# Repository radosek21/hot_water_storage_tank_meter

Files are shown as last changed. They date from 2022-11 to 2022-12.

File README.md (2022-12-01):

# Měřidlo nabití akumulační nádrže
Když jsem si do svého domu nainstaloval topení s kotlem na tuhá paliva a akumulační nádrží Dražice NADO 750/200 v1, celkem mně zajímalo, jak se nádrž chová při nabíjení, vybíjení a v klidu. Dále mne zajímaly tepelné úniky a jak se vrství teplota v nádrži. V neposlední řadě bych ocenil, kdybych dokázal spočítat a ukázat procentuální nabití nádoby pro snazší odhad, kdy se má znovu zatopit.

Dražice NADO 750/200 v1 kombinuje akumulační nádrž topení a zásobník TUV. Disponuje dvěma jímkami pro teplotní čidla. Už při prvních pokusech měření teploty jsem zjistil, že měření pouze se dvěma čidly je pro mé účely naprosto nedostačující. Proto jsem zabrouzdal na internetu a pokusil se najít, zda někdo neřešil podobný problém. Bohužel se mi nepodařilo najít hotové řešení. Ale v nějaké diskuzi jsem narazil na příspěvek, kde diskutér popsal nápad o přilepení několika teplotních čidel přímo na povrch nádoby. Nechal jsem se tímto nápadem inspirovat a sestavil jsem jednoduché měřidlo. S velkým překvapením to překonalo mé očekávání.

## Čidla

Jako první jsem se pustil do čidel. Použil jsem 10 kusů čidel DS18B20, které jsem zapojil paralelně na tří-žílovou duhovou kšandu. Délku kšandy (resp. vzdálenost prvního čidla od posledního) jsem zvolil stejnou, jako je rozteč jímek čidel na nádrži. V mém případě 1049 mm. Tedy při počtu 10ti čidel je rozteč mezi jednotlivými čidly 116,5 mm. Pomocí ALU lepící pásky jsem čidla přilepil k povrchu nádrže tak, aby první a poslední čidlo bylo ve stejné úrovni, jako jsou jímky. Viz obrázek.

Pozn. Bacha na levné čínské kopie DS18B20. Nechal jsem se nachytat a koupil jsem 20ks podezřele levných čidel z eBay. Odchylka od skutečné teploty byla 6-9K. Čidla jsem si pak musel zkalibrovat podle přesnějšího referenčního teploměru. Do firmware jsem proto doplnil proměnnou pro korekci čidel. Více o kopiích DS18B20 je popsáno třeba zde: https://github.com/cpetrich/counterfeit_DS18B20

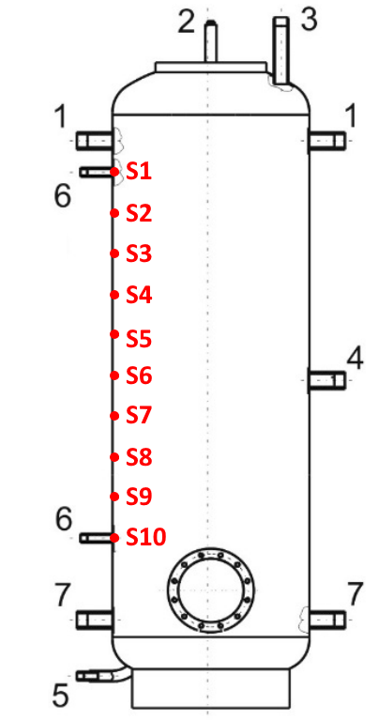
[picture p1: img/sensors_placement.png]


## Měřidlo

Pro sběr a vyhodnocení dat jsem použil modul Arduino Wemos kompatibilní. Modul má integrovanou WiFi a má dostatečný počet GPIO. Jako zobrazovač jsem použil Arduino hodinový displej s řadičem TM1637. Aby to nejen fungovalo, ale i vypadalo, vytisknul jsem si na 3d tiskárně malou krabičku, do které se vše pohodlně vejde. Data pro 3d tisk jsou v adresáři *housing*.

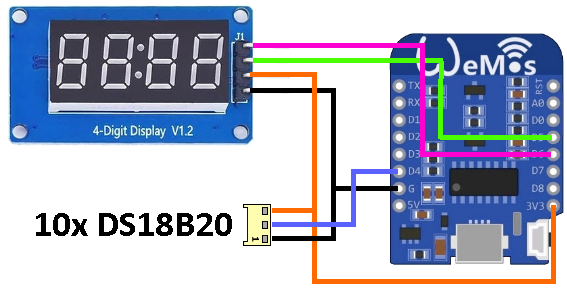
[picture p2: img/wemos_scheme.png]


Schéma zapojení měřidla

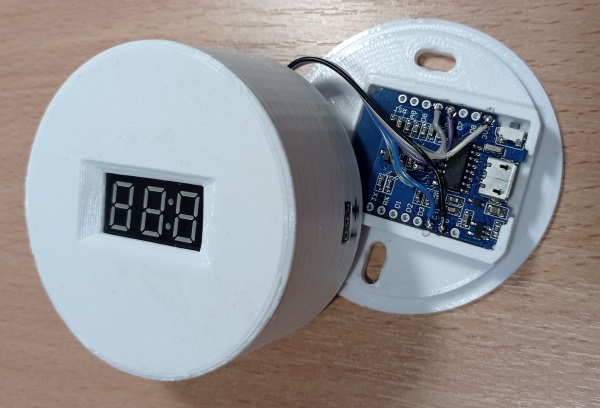
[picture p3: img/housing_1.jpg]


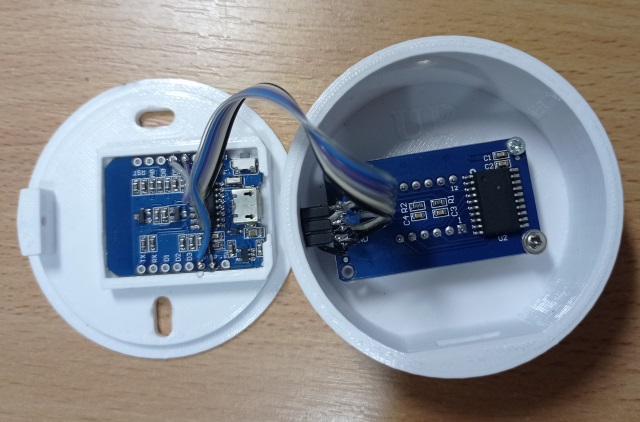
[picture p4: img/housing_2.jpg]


Vnitřní zapojení krabičky

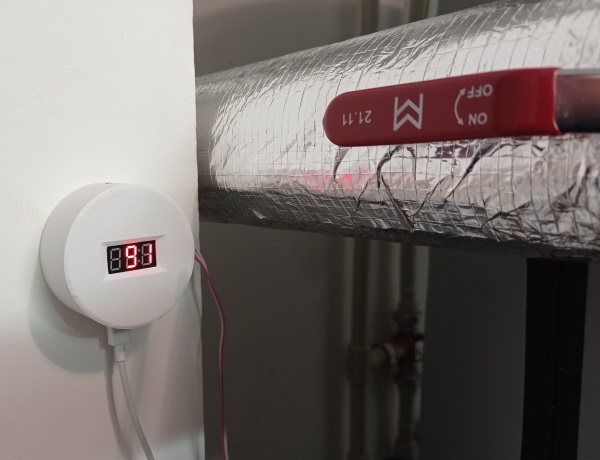
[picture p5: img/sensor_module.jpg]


Měřidlo v provozu

## Fimware pro Wemos

Zdrojové kódy měřidla se nacházejí v adresáři *wemos_18B20_sensor*. Projektový soubor *wemos_18B20_sensor.ino* zajišťuje funkčnost a soubory *peripherals.cpp* a *peripherals.h* zajišťují obsluhu teplotních čidel a displeje. Aby bylo možné zkompilovat tento projekt, je zapotřebí do Aurduino IDE doinstalovat podporu desky esp8266 a následně vybrat správnou Arduino desku. V mém případě **LOLIN(WEMOS) D1 mini (clone)**, který jsem kopil na eBay. 

Dále je zapotřebí doinstalovat knihovny:

-  TM1637 - Grove 4-Digital Display by Seeed Studio
- OneWire by Paul Stroffregen
- DallasTemperature by Miles Burton

Ve zdrojovém kódu je zapotřebí doplnit:

- SSID a heslo WiFi, do které se bude měřidlo připojovat
- seznam adresy všech deseti čidel DS18B20 (seznam **sensorsAddr[TEMP_SENSORS_CNT]**)
- případné korekce čidel (seznam **sensorsCorrections[TEMP_SENSORS_CNT]**)

Veškerá měřená i vypočtená data z čidel jsou dostupná přes ModbusTCP (port 502).

#### Input registry:

| Jméno registru | Adresa | Jednotka | Popis |
| --- | --- | --- | --- |
| Sensors count | 1 | | Počet právě dostupných čidel DS18B20 |
| Average temperature | 2 | 0.01°C | Průměrná teplota všech čidel |
| Capacity | 3 | 0.01% | Procentuální nabití nádrže |
| Sensors data | 100..109 | 0.01°C | Teploty jednotlivých čidel S1 - S10  |

#### Holding registry:

| Jméno registru | Adresa | Jednotka | Popis |
| --- | --- | --- | --- |
| Min average temperature | 1 | 1°C | Nejnižší průměrná teplota v nádrži pro výpočet nabití. Parametr **MinAvgTemp** |
| Max average temperature | 2 | 1°C | Nevyšší průměrná teplota v nádrži pro výpočet nabití. Parametr **MaxAvgTemp** |

Konfigurační parametry min a max average temperature jsou uloženy ve vnitřní EEPROM procesoru. Jejich defaultní hodnoty jsou 40 a 77°C.

## Sběr dat

Pro snadný sběr a následnou analýzu dat jsem napsal jednoduchý Python skript, který každých 10s periodicky vyčítá data z měřidla a ukládá je do MySQL (resp. MariaDb) databáze. Použití relační databáze pro tyto účely není úplně šťastné, ale u mne doma to bylo nejsnazší řešení, protože můj NAS server ji nativně podporuje. Pro omezení počtu mysql queries skript posílá nasbíraná data jednou za minutu. Zdrojové kódy se nacházejí v adresáři *data_acquire*. Hlavní program se nachází v souboru *HeaterDAQ.py*. V tomto souboru je třeba doplnit následující:

- mysql.host - adresa MySQL serveru
- mysql.user - uživatelské jméno do databáze
- mysql.passwd - heslo do databáze
- dbName - jméno databáze, do které se budou ukládat data
- dbTable - tabulka výše zmíněné databáze, do které se budou ukládat data

## Analýza dat a výpočet nabití nádrže

K analýze a vizualizaci dat jsem použil Grafanu. Nabízí dost možností a funkcí pro práci s daty. 

Pro výpočet procentuálního nabití nádrže jsem po zvážení několika algoritmů dospěl k závěru, že nejvhodnějším, a také nejjednodušším, řešením je použití obyčejného aritmetického průměru teplot všech čidel a následná transformace lineární funkcí na procenta. Algoritmus je výpočetně velmi jednoduchý a má dostatečnou přesnost a stabilitu.

Výpočet vypadá následovně:
$$
cap = (avg[S1:S10] - MinAvgTemp) / (MaxAvgTemp  - MinAvgTemp) * 100
$$

Parametry **MaxAvgTemp** a **MinAvgTemp** jsou v uloženy ve vnitřní paměti EEPROM procesoru. Jsou konfigurovatelné pomocí holding registrů 1 a 2.

Data z Grafany pak vypadají například takto:

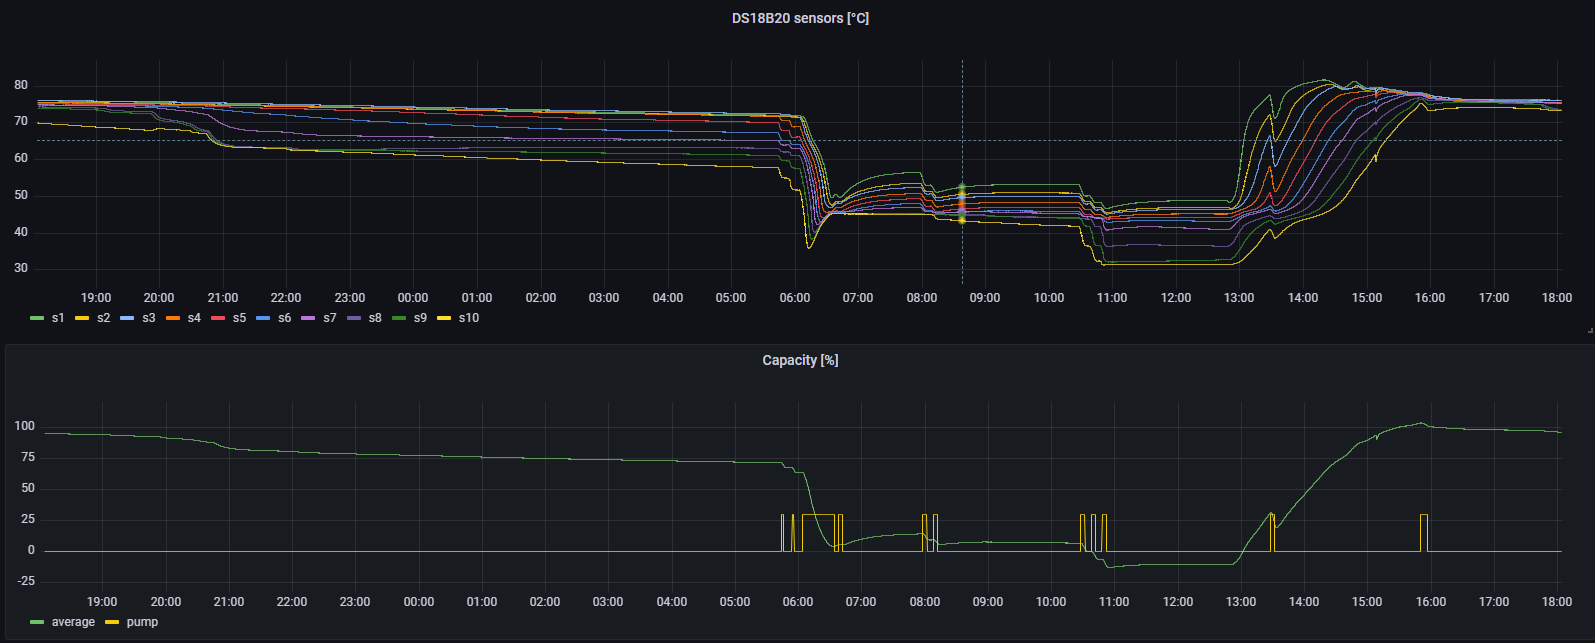
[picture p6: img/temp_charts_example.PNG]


Horní graf ukazuje data z jednotlivých čidel. Dolní graf ukazuje procentuální nabití nádrže a cykly spínání oběhového čerpadla. V grafech je od začátku viděl pozvolné vybíjení nádrže vlivem teplených ztrát. V cca 21hod je vidět drobný odběr teplé vody a v 6 hod ráno se sepnulo oběhové čerpadlo a topilo na komfortní teplotu. Následně ve 13 hod jsem zatopil v kotli. 

## Závěr

Nejen v grafech z Grafany je vidět, že měřidlo teploty ukazuje teplotu poměrně dobře. Výpočet procentuálního nabití nádrže odpovídá aktuálnímu stavu a z grafu je patrné, že tato hodnota nijak nekolísá a je velmi stabilní. Měřidlo nadmíru splnilo mé očekávání a informace na displeji je natolik intuitivní, že to pochopila i moje žena. Inu, i z malého nápadu se dá udělat celkem hezký projekt. ;-)

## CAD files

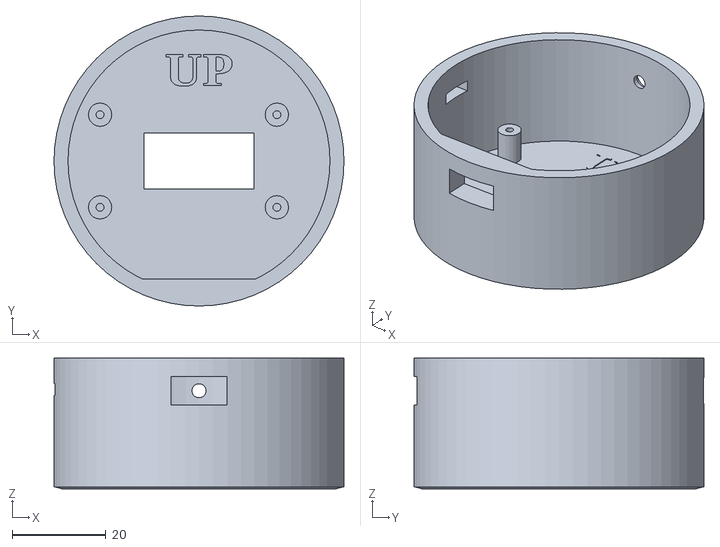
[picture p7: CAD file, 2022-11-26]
housing/Tank capacity meter cover.stl
62.0 x 62.0 x 28.0

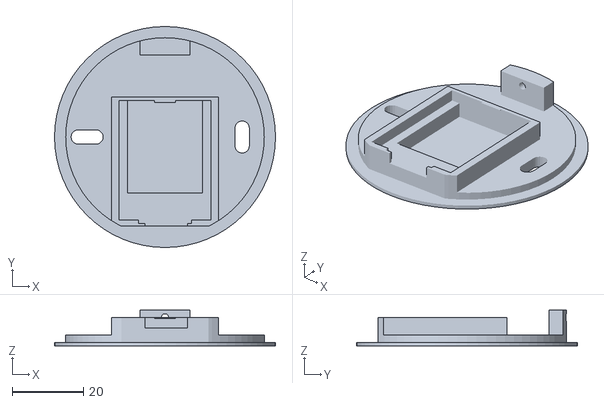
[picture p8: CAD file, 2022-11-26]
housing/Tank capacity meter base.stl
62.0 x 62.0 x 10.0

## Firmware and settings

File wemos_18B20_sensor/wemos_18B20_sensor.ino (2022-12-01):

// LOLIN(WEMOS) D1 mini (clone)

#include <ESP8266WiFi.h>
#include <ModbusIP_ESP8266.h>
#include "peripherals.h"
#include <EEPROM.h>

#define EEPROM_MAGIC_NUMBER                 0xDEADBEEF
#define DEFAULT_HEATER_TANK_MIN_AVG_TEMP    40
#define DEFAULT_HEATER_TANK_MAX_AVG_TEMP    77

#define MB_IREG_SENSORS_CNT_ADDR   1
#define MB_IREG_AVG_TEMP_ADDR      2
#define MB_IREG_CAPACITY_ADDR      3
#define MB_IREG_SENSORS_ADDR       100
#define MB_HREG_MIN_TEMP_ADDR      1
#define MB_HREG_MAX_TEMP_ADDR      2


typedef struct {
  uint32_t magic;
  uint16_t minAvgTemp;
  uint16_t maxAvgTemp;
} EepromData_t;


// Set WiFi credentials
#define WIFI_SSID "MY SSID"
#define WIFI_PASS "MY PASSWORD"

// List of the temperature sensors addresses
String sensorsAddr[TEMP_SENSORS_CNT] = {
  "2801ED0F00000085",
  "283AEC0F0000005D",
  "285BF60F00000068",
  "2827FF0F0000007E",
  "28D7FD0F0000008F",
  "2870FB0F000000CA",
  "2804F10F00000033",
  "2819FE0F0000004D",
  "28A2F00F00000010",
  "28CDF70F000000A6",
};

// Put temperature corrections here, if needed.
float sensorsCorrections[TEMP_SENSORS_CNT] = {
  0,
  0,
  0,
  0,
  0,
  0,
  0,
  0,
  0,
  0,
};

ModbusIP mb;
long ts;
EepromData_t eepromData;
uint16_t iRegAvgTemp;
uint16_t iRegSensorsCnt;

void setup() {
  int timeout = millis() + 60000;
  iRegAvgTemp = 0;
  iRegSensorsCnt = 0;
  Serial.begin(115200);
  Serial.println("");
  
  
  delay(1000);
  readParams();
  tempSensors.begin();

  // Begin WiFi
  WiFi.begin(WIFI_SSID, WIFI_PASS);
  // Connecting to WiFi...
  Serial.print("Connecting to ");
  Serial.print(WIFI_SSID);
  // Loop continuously while WiFi is not connected
  while ((WiFi.status() != WL_CONNECTED) && (millis() < timeout)) {
    delay(100);
    Serial.print(".");
    display.progressIter();
  }

  Serial.println();
  if (WiFi.status() != WL_CONNECTED) {
    Serial.print("Connected! IP address: ");
    Serial.println(WiFi.localIP());
  } else {
    Serial.println("WIFI connection timed out!");
  }

  // Start Modbus TCP server
  mb.server();    
  // Register modbus input registers
  mb.addIreg(MB_IREG_SENSORS_CNT_ADDR, 0);
  mb.addIreg(MB_IREG_AVG_TEMP_ADDR, 0);
  mb.addIreg(MB_IREG_CAPACITY_ADDR, 0);
  mb.addIreg(MB_IREG_SENSORS_ADDR, 0, TEMP_SENSORS_CNT); 
  mb.addHreg(MB_HREG_MIN_TEMP_ADDR, eepromData.minAvgTemp);
  mb.addHreg(MB_HREG_MAX_TEMP_ADDR, eepromData.maxAvgTemp);
  mb.onSetHreg(MB_HREG_MIN_TEMP_ADDR, cbWriteMinTemp, 1);
  mb.onSetHreg(MB_HREG_MAX_TEMP_ADDR, cbWriteMaxTemp, 1);
  
  // Bind all DS18B20 temperature sensors
  for (int index = 0; index < TEMP_SENSORS_CNT; index++) {
    DeviceAddress addr;
    for (int i = 0; i < 8; i++ ) {
      addr[i] = StrToHex(sensorsAddr[index].substring(i*2, i*2+2)); 
    }
    if (!tempSensors.bind(addr, index)) {
      Serial.print("Sensor address ");
      Serial.print(sensorsAddr[index]);
      Serial.println(" not bound!!!");
    }
  }
  ts = millis();
}

void loop() {
  float temp;
  float avgTemp = 0;
  int avgCnt = 0;
  float heatCap;
  
  // Modbus TCP handler
  mb.task();
  
  //Read every two seconds
  if (millis() >= ts) {
    // Schedule next temperature sensors reading
    ts = millis() + 2000;
    
    // Send command to all the sensors for temperature conversion
    tempSensors.requestTemperatures();
    // 
    for (int i = 0;  i < TEMP_SENSORS_CNT;  i++) {
      temp = tempSensors.getTemp(i) + sensorsCorrections[i];
      // If temperature value is valid
      if ((temp > 0) && (temp < 120)) {
        Serial.print("Sensor ");
        Serial.print(i+1);
        Serial.print(" : ");
        Serial.print(temp);
        Serial.println("C");
        mb.Ireg(MB_IREG_SENSORS_ADDR + i, (int16_t)(temp * 100));
        avgTemp += temp;
        avgCnt++;
      }
    }
    mb.Ireg(MB_IREG_SENSORS_CNT_ADDR, avgCnt);  
    if (avgCnt > (TEMP_SENSORS_CNT / 2)) {
      // Do an average temperature when at least half of sensors are present
      avgTemp /= avgCnt;
      // Transform measured temperature value to the percentage of heater tank capacity
      heatCap = ((avgTemp - eepromData.minAvgTemp) * 100 / (eepromData.maxAvgTemp - eepromData.minAvgTemp));
      mb.Ireg(MB_IREG_AVG_TEMP_ADDR, (int16_t)(avgTemp * 100));
      mb.Ireg(MB_IREG_CAPACITY_ADDR, (int16_t)(heatCap * 100));
      // Show current capacity
      display.number((int)constrain(heatCap, -150, 999), 1);
    } else {
      // Half of sensors are missed. Display "---"
      display.code(display.emptyPattern);
      mb.Ireg(MB_IREG_AVG_TEMP_ADDR, 0);
      mb.Ireg(MB_IREG_CAPACITY_ADDR, 0);
    }
  }
}

int StrToHex(String str) {
  char buf[3];
  str.toCharArray(buf, 3);
  return (int)strtol(buf, 0, 16);
}

void readParams()
{
  //Init EEPROM
  EEPROM.begin(sizeof(EepromData_t));
  Serial.println("EEPROM: reading");
  EEPROM.get(0, eepromData);
  if(eepromData.magic != EEPROM_MAGIC_NUMBER) {
    Serial.println("EEPROM: using defaults.");
    eepromData.magic = EEPROM_MAGIC_NUMBER;
    eepromData.minAvgTemp = DEFAULT_HEATER_TANK_MIN_AVG_TEMP;
    eepromData.maxAvgTemp = DEFAULT_HEATER_TANK_MAX_AVG_TEMP;
  }
  EEPROM.end();
}

void writeParams()
{
  //Init EEPROM
  Serial.println("EEPROM: writing");
  EEPROM.begin(sizeof(EepromData_t));
  EEPROM.put(0, eepromData);
  EEPROM.commit();
  EEPROM.end();
}

uint16_t cbWriteMinTemp(TRegister* reg, uint16_t val) {
  Serial.print("Write min temp: ");
  Serial.println(val);
  eepromData.minAvgTemp = val;
  writeParams();
  return val;
}

uint16_t cbWriteMaxTemp(TRegister* reg, uint16_t val) {
  Serial.print("Write max temp: ");
  Serial.println(val);
  Serial.println(val);
  eepromData.maxAvgTemp = val;
  writeParams();
  return val;
}

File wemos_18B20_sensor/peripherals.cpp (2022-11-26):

#include "peripherals.h"


#define TM1637_CLK    ( D6 )
#define TM1637_DIO    ( D5 )


//-------------------------------------------------------------------------
// Display
//-------------------------------------------------------------------------
Display::Display():
tm(TM1637_CLK, TM1637_DIO),
progressCnt(0)
{
  tm.init();
  tm.set(2); // Set brightness level
}

void Display::code(uint8_t BitAddr, int8_t code)
{
  tm.start();          //start signal sent to TM1637 from MCU
  tm.writeByte(ADDR_FIXED);//
  tm.stop();           //
  tm.start();          //
  tm.writeByte(BitAddr|0xc0);//
  tm.writeByte(code + ((tm._PointFlag == POINT_ON) ? 0x80 : 0x00));//
  tm.stop();            //
  tm.start();          //
  tm.writeByte(tm.Cmd_DispCtrl);//
  tm.stop();           //
}

void Display::code(const uint8_t *codes)
{
  code((uint8_t*)codes);
}

void Display::code(uint8_t *codes)
{
  for (int i=0; i < 4; i++) {
     code(i, codes[i]);
  }
}

void Display::number(int num, int pos)
{
  tm.point(false);
  for (int i = 0; i < pos; i++) {
    code(4-pos, DISP_CHAR_Empty);
  }
  if (num >= 1) {
    tm.display(3-pos, num % 10);
  } else {
    code(3-pos, DISP_CHAR_Empty);
  }
  if (num >= 10) {
    tm.display(2-pos, num / 10 % 10);   
  } else {
    code(2-pos, DISP_CHAR_Empty);
  }
  if (num >= 100) {
    tm.display(1-pos, num / 100 % 10);   
  } else {
    code(1-pos, DISP_CHAR_Empty);
  }
  if (num >= 1000) {
    tm.display(0-pos, num / 1000 % 10);
  } else {
    code(0-pos, DISP_CHAR_Empty);
  }
}

void Display::progressIter()
{
  for (int i = 0; i < DISP_COUNT; i++) {
    code(i, progressPattern[progressCnt][i]);
  }
  progressCnt++;
  if (progressCnt >= 10) {
    progressCnt = 0;
  }
}

//-------------------------------------------------------------------------
// Temperature sensors
//-------------------------------------------------------------------------
TempSensors::TempSensors():
oneWire(2),
ds18b20(&oneWire)
{

}

void TempSensors::begin()
{
  memset(bindings, 255, TEMP_SENSORS_CNT);
  ds18b20.begin();
  Serial.println("Locating devices...");
  Serial.print("Found ");
  deviceCount = ds18b20.getDeviceCount();
  Serial.print(deviceCount, DEC);
  Serial.println(" devices.");
  Serial.println("");
  Serial.println("Printing addresses...");
  for (int i = 0;  i < deviceCount;  i++) {
    Serial.print("Sensor ");
    Serial.print(i+1);
    Serial.print(" : ");
    ds18b20.getAddress(deviceAddress[i], i);
    printAddress(deviceAddress[i]);
  }
}

bool TempSensors::bind(DeviceAddress addr, uint8_t id)
{
  bool result = false;
  for (int i = 0; i < TEMP_SENSORS_CNT; i++) {
    if (memcmp(addr, deviceAddress[i], 8) == 0) {
      bindings[id] = i;
      Serial.print("Bound ");
      Serial.print(i);
      Serial.print(" to ");
      Serial.println(id);
      result = true;
    }
  }
  return result;
}

float TempSensors::getTemp(uint8_t index)
{
  if(bindings[index] == 255) {
    return DEVICE_DISCONNECTED_C;
  }
  return ds18b20.getTempCByIndex(bindings[index]);
}

void TempSensors::printAddress(uint8_t *addr)
{ 
  for (uint8_t i = 0; i < 8; i++)
  {
    // zero pad the address if necessary
    if (addr[i] < 16) Serial.print("0");
    Serial.print(addr[i], HEX);
  }
  Serial.println("");
}

//-------------------------------------------------------------------------
// Peripherals singletons
//-------------------------------------------------------------------------
Display display;
TempSensors tempSensors;

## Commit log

2022-11-26 Added Wemos Arduino temperature sensors project
2022-11-26 Added Wemos temperature sensor schematic
2022-11-26 Added housing 3d prints
    [Tank capacity meter base.stl, Tank capacity meter cover.stl]
